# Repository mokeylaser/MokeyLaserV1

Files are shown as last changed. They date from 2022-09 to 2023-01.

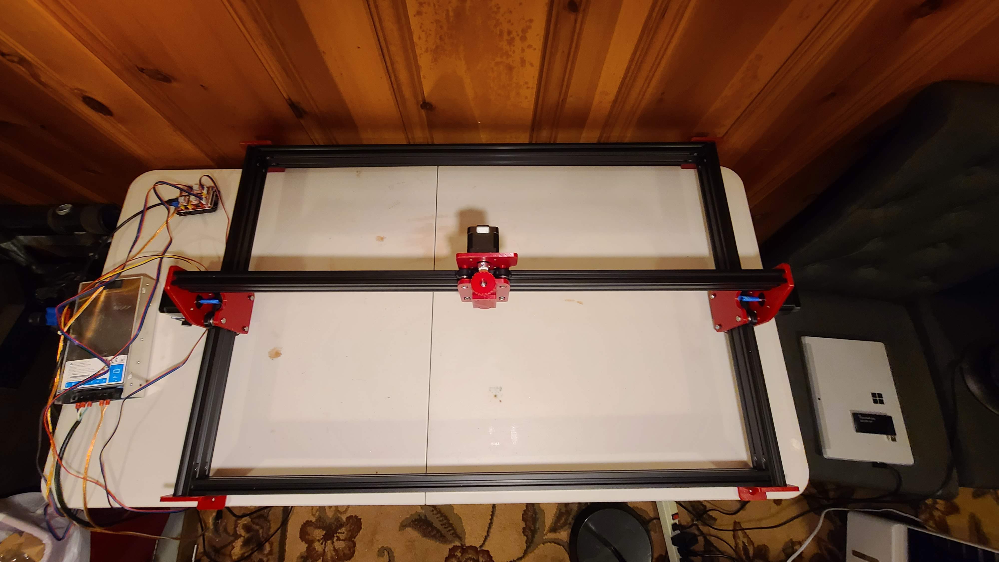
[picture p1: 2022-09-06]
MokeyLaserV1_Images/20220827_191324.jpg

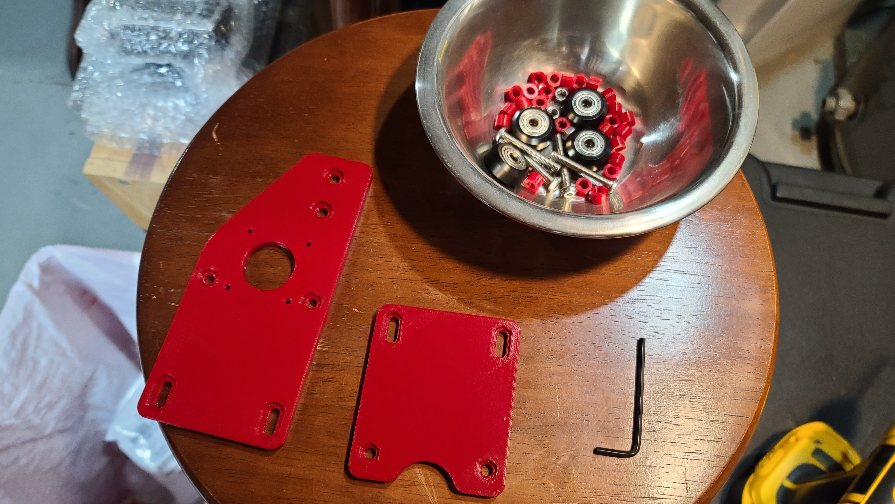
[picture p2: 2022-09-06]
MokeyLaserV1_Images/20220822_205706.jpg

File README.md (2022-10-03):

# MokeyLaserV1
The files needed to build MokeyLaser V1, including 3D models

NOTE: Most lasers, including those shown in my videos, are capable of severely damaging or blinding human eyes and burning or damaging human skin. Any individual working with these devices must be aware of these laser safety issues and take appropriate measures to protect both themselves and others. Read and follow the manufacturer's safety guidelines for your laser. I am NOT responsible for any damage or injury to yourself or any other person resulting from the use, assembly, or operation of any device built from or inspired by my designs. 

Here is the list of purchased parts:
	2M Motor Connecting Cables (pack of 4)	$12.59	Amazon	https://www.amazon.com/dp/B07SLPLPL2?psc=1&ref=ppx_yo2ov_dt_b_product_details
	T-Nuts, 240 Pieces, 2020, M3 M4 M5	$9.98	Amazon	https://www.amazon.com/dp/B08CHJMWP5?psc=1&ref=ppx_yo2ov_dt_b_product_details
	Pan Head Machine Screws, M5-0.8x100mm	$7.99	Amazon	https://www.amazon.com/dp/B07YDJHDP6?psc=1&ref=ppx_yo2ov_dt_b_product_details
	GT2 Pulleys, 20 Teeth, 5mm bore (pack of 5)	$5.99	Amazon	https://www.amazon.com/dp/B077GNZK3J?psc=1&ref=ppx_yo2ov_dt_b_product_details
	2040 Aluminum Extrusion, 1000mm V Slot (pack of 5)	$79.99	Amazon	https://www.amazon.com/dp/B09SHF6VYQ?psc=1&ref=ppx_yo2ov_dt_b_product_details
	GT2 Timing Belt, 5M, 6mm width	$12.99	Amazon	https://www.amazon.com/dp/B08R93QQ8Z?psc=1&ref=ppx_yo2ov_dt_b_product_details
	Printer rollers, V Slot gantry wheel, 625zz (pack of 13)	$11.11	Amazon	https://www.amazon.com/dp/B08B4JDB67?psc=1&ref=ppx_yo2ov_dt_b_product_details
	CNC Shield V3, with A4988 driver modules	$10.99	Amazon	https://www.amazon.com/dp/B07TT3C3HB?psc=1&ref=ppx_yo2ov_dt_b_product_details
	NEMA 17 Stepper Motor, Bipolar, 1.5A, 59.5oz.in (pack of 3)	$28.99	Amazon	https://www.amazon.com/dp/B088BG2QFG?psc=1&ref=ppx_yo2ov_dt_b_product_details
	SainSmart FL55 Laser Module, 455nm, with TTL/PWM 	$159.00	Amazon	https://www.amazon.com/gp/product/B07VHJ7JNW/ref=ppx_yo_dt_b_search_asin_title?ie=UTF8&psc=1
	T-Slot inside corner connector for 2020 extrusion (pack of 20)	$15.99	Amazon	https://www.amazon.com/dp/B07F2K8SN7?psc=1&ref=ppx_yo2ov_dt_b_product_details
	Longrunner mechanical endstop (limit switch) kit (pack of 6)	$9.99	Amazon	https://www.amazon.com/gp/product/B06XTB7WMK/ref=ppx_yo_dt_b_search_asin_title?ie=UTF8&psc=1
	Arduino Uno R3 board, ATmega328p	$17.99	Amazon	https://www.amazon.com/ELEGOO-Board-ATmega328P-ATMEGA16U2-Compliant/dp/B01EWOE0UU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
	Amazon Total	$383.59		
				
	Socket Head Cap Screw: M5-0.80 Tr Size, 35 mm Lg (pack of 50)	$11.62	Grainger	https://www.grainger.com/product/53GJ20
	Socket Head Cap Screw: M3-0.50 Tr Size, 8 mm Lg (pack of 50)	$2.00	Grainger	https://www.grainger.com/product/53GJ01
	Socket Head Cap Screw: M5-0.80 Tr Size, 10 mm Lg (pack of 50)	$4.20	Grainger	https://www.grainger.com/product/53GJ15
	Hex Nut: Plain, 18-8, Stainless Steel, M5-0.80 Thread (pack of 50)	$1.20	Grainger	https://www.grainger.com/product/22YK31
	Grainger Total	$19.02		
	Grand Total	$402.61		
MokeyLaser_V1_Assembly_2022-Sep-06_03-15-41PM

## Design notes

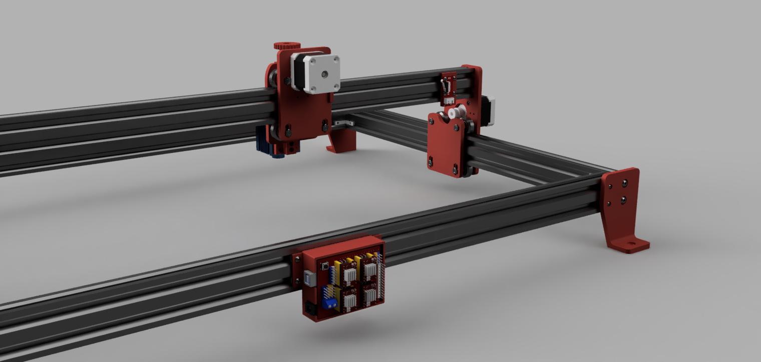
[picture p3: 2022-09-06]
MokeyLaserV1_Images/Arduino and CNC Shield view.jpg

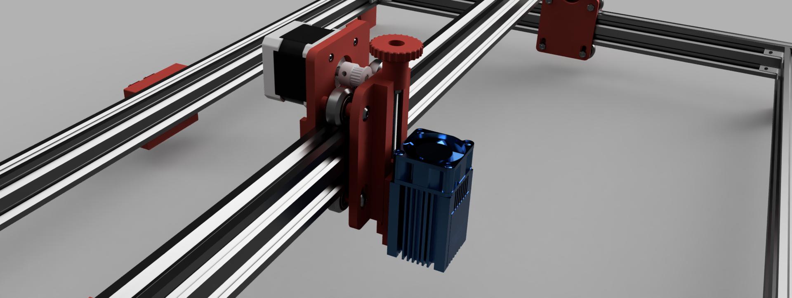
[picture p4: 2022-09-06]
MokeyLaserV1_Images/X-Axis view.jpg

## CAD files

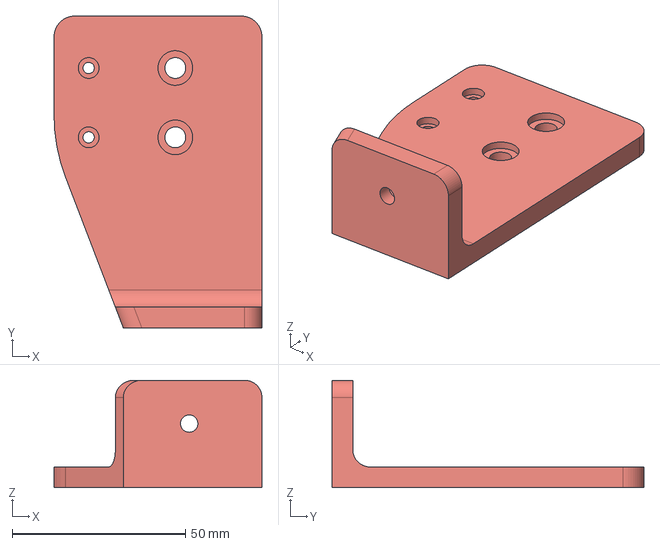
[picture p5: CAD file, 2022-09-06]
CAD_Models_V1/09 Right Leg v1.step
60.0 x 90.0 x 31.0 mm

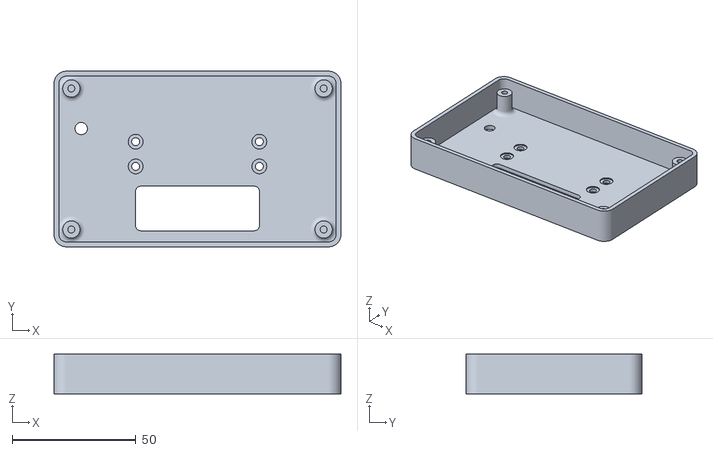
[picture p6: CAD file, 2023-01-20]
MokeyLaser_v1.1/Display Holder TS35-R-V2 v5.stl
116.0 x 71.0 x 16.0

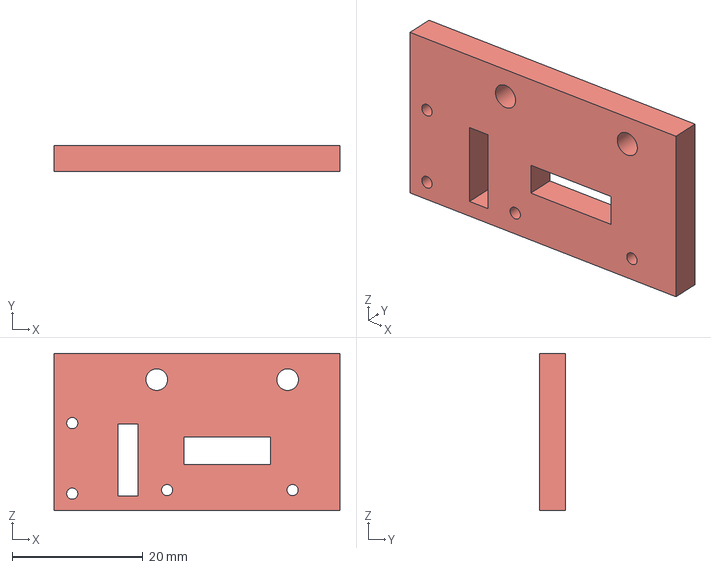
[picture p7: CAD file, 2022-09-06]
CAD_Models_V1/Limit switch mount 4mm v1.step
43.7 x 4.00 x 24.0 mm

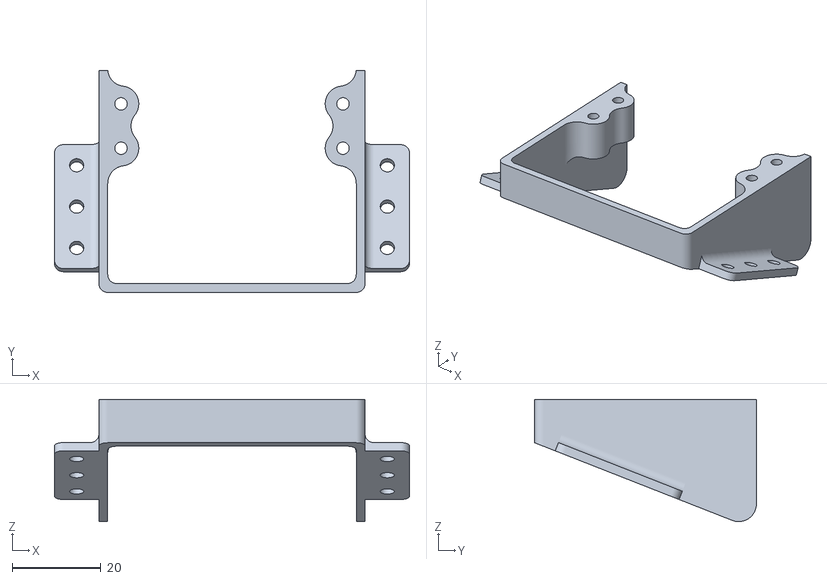
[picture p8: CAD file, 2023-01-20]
MokeyLaser_v1.1/Display Holder TS35-R-V2 Bracket v5.stl
80.0 x 50.0 x 27.5

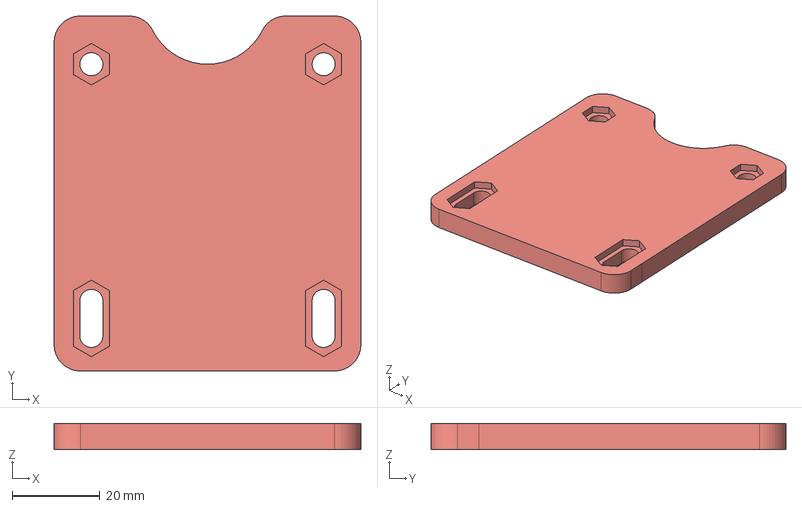
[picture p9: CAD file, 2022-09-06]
CAD_Models_V1/08 Y-Drive Side Panel v1.step
70.0 x 81.0 x 6.00 mm

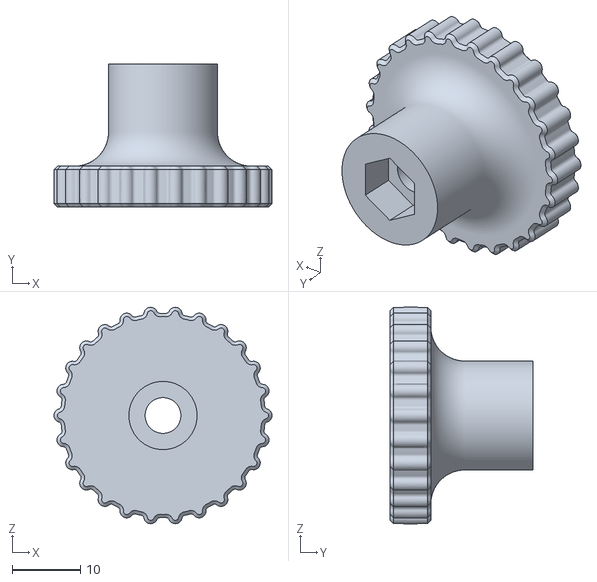
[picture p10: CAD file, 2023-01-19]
MokeyLaser_v1.1/04 Laser Focus Knob v1.stl
32.0 x 21.0 x 31.8

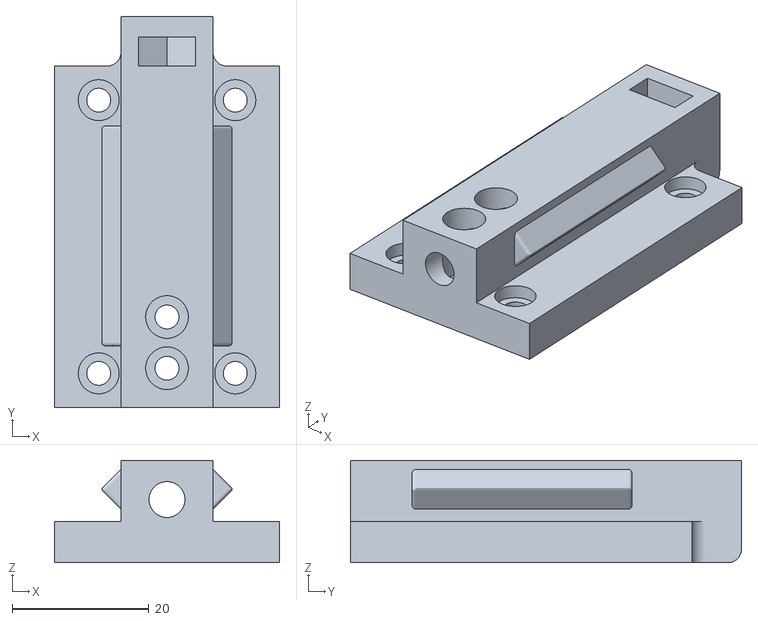
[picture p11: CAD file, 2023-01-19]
MokeyLaser_v1.1/01 Laser Mount 20mm x 40mm M3 v1.stl
33.0 x 57.2 x 15.0

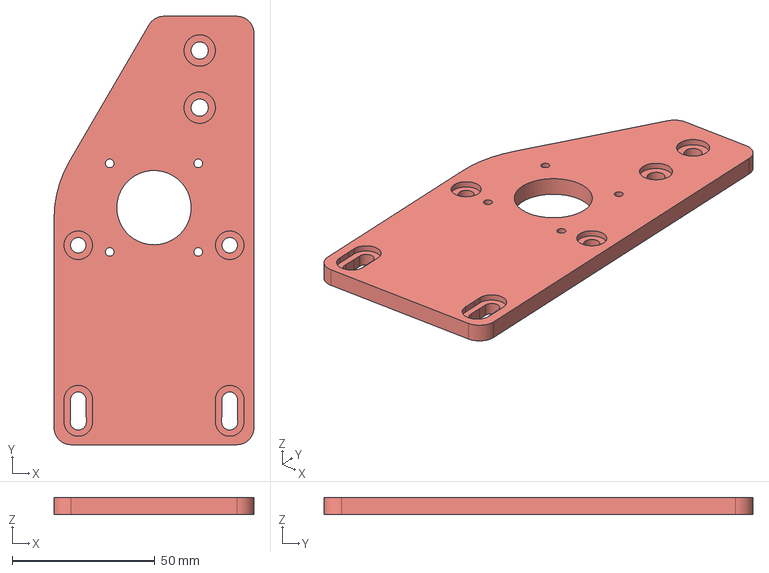
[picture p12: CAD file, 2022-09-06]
CAD_Models_V1/06 Y-Drive Panel R v1.step
70.0 x 150.0 x 6.00 mm

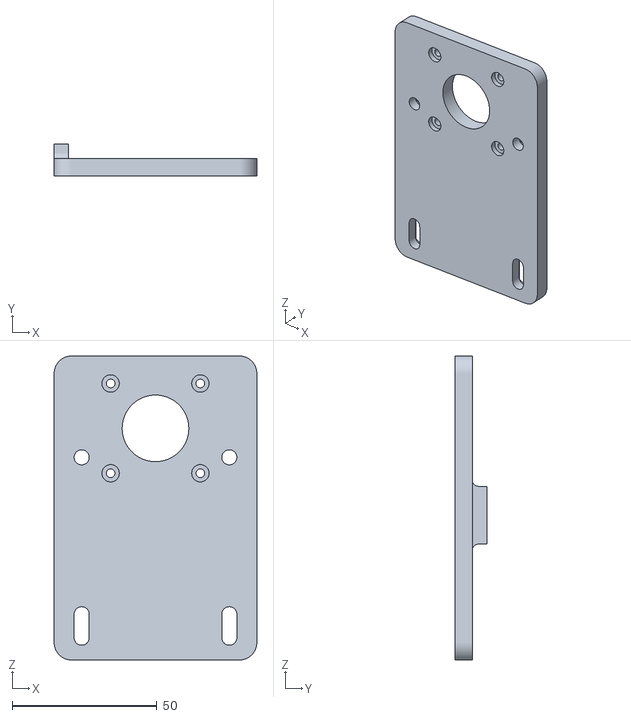
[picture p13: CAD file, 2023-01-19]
MokeyLaser_v1.1/03 X-Axis Stepper Mount v1.stl
70.0 x 11.0 x 105.0

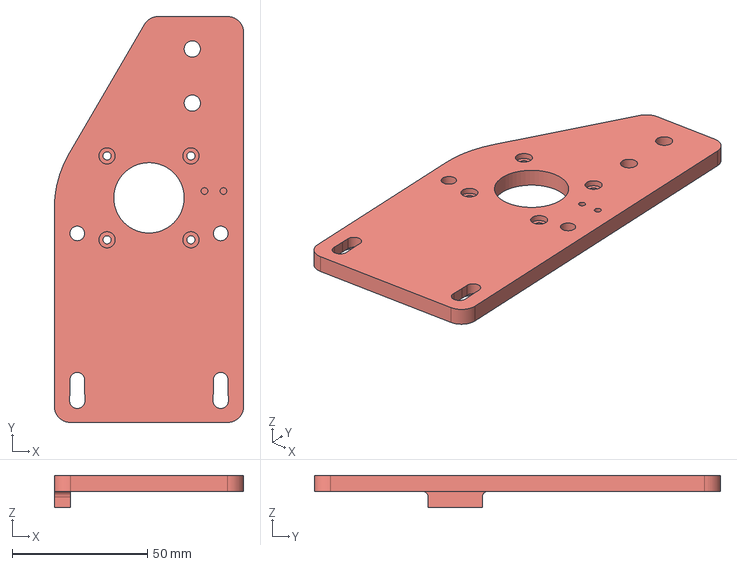
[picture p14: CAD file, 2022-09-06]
CAD_Models_V1/06 Y-Drive Panel L v1.step
70.0 x 150.0 x 12.0 mm

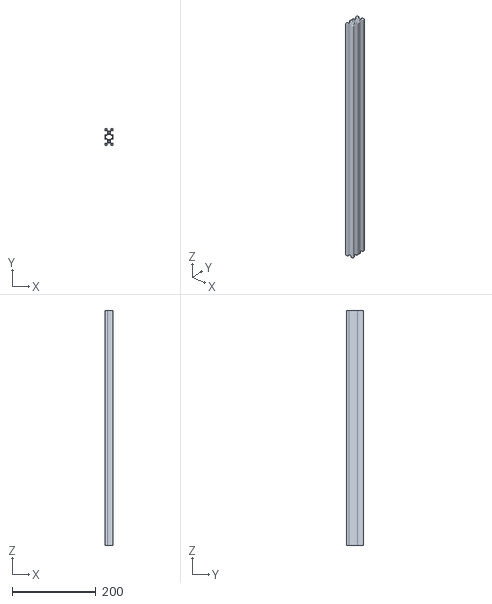
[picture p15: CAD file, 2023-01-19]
MokeyLaser_v1.1/do_not_print_2040 V-Slot 560mm v3.stl
20.0 x 40.0 x 560.0

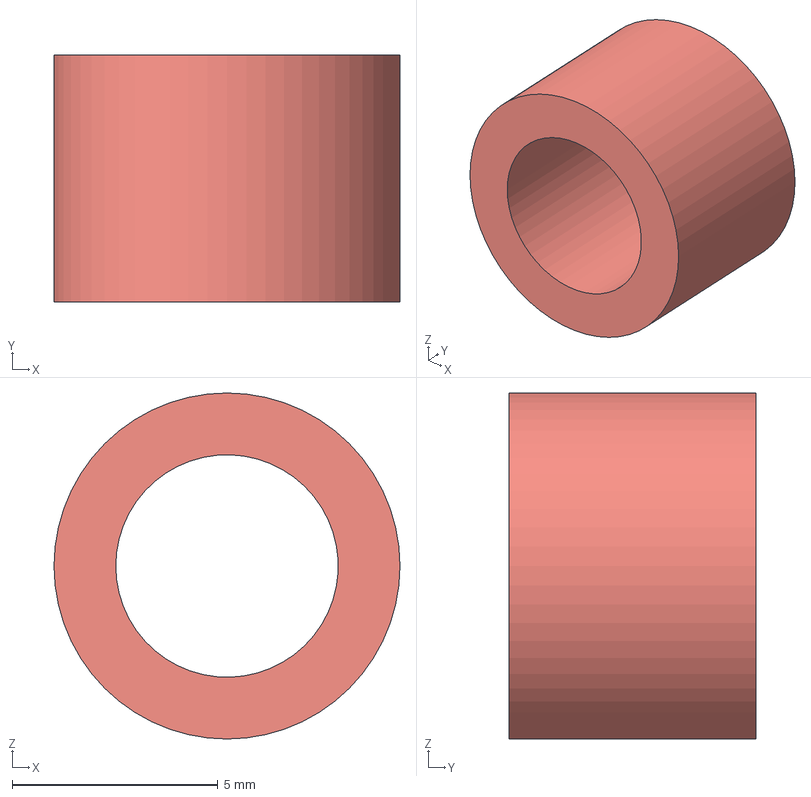
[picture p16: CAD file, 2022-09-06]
CAD_Models_V1/05 V-Wheel Bushing v1.step
8.40 x 6.00 x 8.40 mm

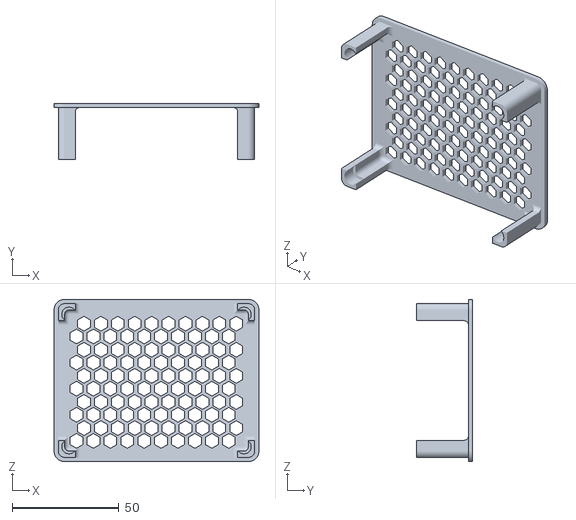
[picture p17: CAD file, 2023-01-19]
MokeyLaser_v1.1/DLC32 Enclosrue Lid.stl
96.0 x 26.4 x 76.0

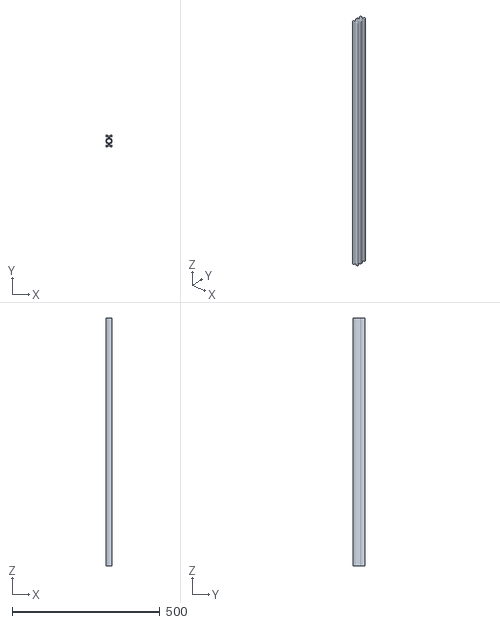
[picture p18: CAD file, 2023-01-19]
MokeyLaser_v1.1/do_not_print_2040 V-Slot 839mm v3.stl
20.0 x 40.0 x 839.0

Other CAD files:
CAD_Models_V1/09 Left Leg v1.step
MokeyLaserV1_STLs/01 Laser Mount v1.stl
CAD_Models_V1/03 X-Axis Stepper Mount v1.step
CAD_Models_V1/02 Laser holder base v1.step
CAD_Models_V1/01 Laser Mount v1.f3d
CAD_Models_V1/01 Laser Mount v1.step
CAD_Models_V1/02 Laser holder base v1.f3d
CAD_Models_V1/03 X-Axis Stepper Mount v1.f3d
CAD_Models_V1/04 Laser Focus Knob v1.f3d
CAD_Models_V1/04 Laser Focus Knob v1.step
CAD_Models_V1/05 V-Wheel Bushing v1.f3d
CAD_Models_V1/06 Y-Drive Panel L v1.f3d
CAD_Models_V1/06 Y-Drive Panel R v1.f3d
CAD_Models_V1/08 Y-Drive Side Panel v1.f3d
CAD_Models_V1/09 Left Leg v1.f3d
CAD_Models_V1/09 Right Leg v1.f3d
CAD_Models_V1/Limit switch mount 4mm v1.f3d
CAD_Models_V1/Uno and CNC Shield holder v2.f3d
CAD_Models_V1/Uno and CNC Shield holder v2.step
MokeyLaserV1_STLs/02 Laser holder base v1.stl
MokeyLaserV1_STLs/03 X-Axis Stepper Mount v1.stl
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

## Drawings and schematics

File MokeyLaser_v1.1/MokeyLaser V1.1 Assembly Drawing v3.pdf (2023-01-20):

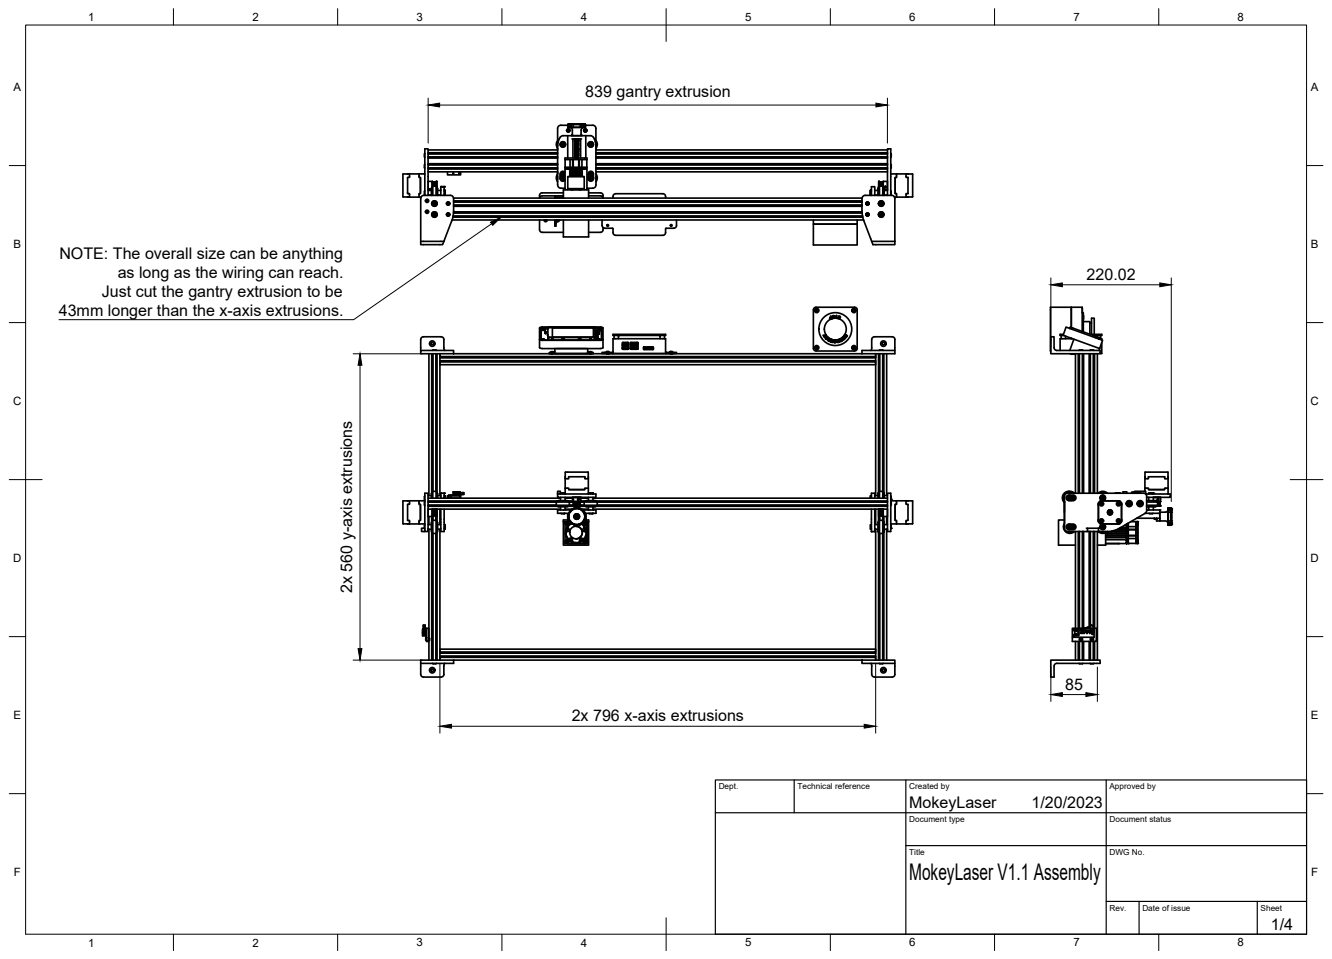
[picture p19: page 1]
Dept.; Technical reference; Created by; Approved by; Document type; Document status; Title; DWG No.; Rev.; Date of issue; Sheet; MokeyLaser V1.1 Assembly; 2x 796 x-axis extrusions; 839 gantry extrusion

NOTE: The overall size can be anything

as long as the wiring can reach.
Just cut the gantry extrusion to be
43mm longer than the x-axis extrusions.

MokeyLaser 2x 560 y-axis extrusions

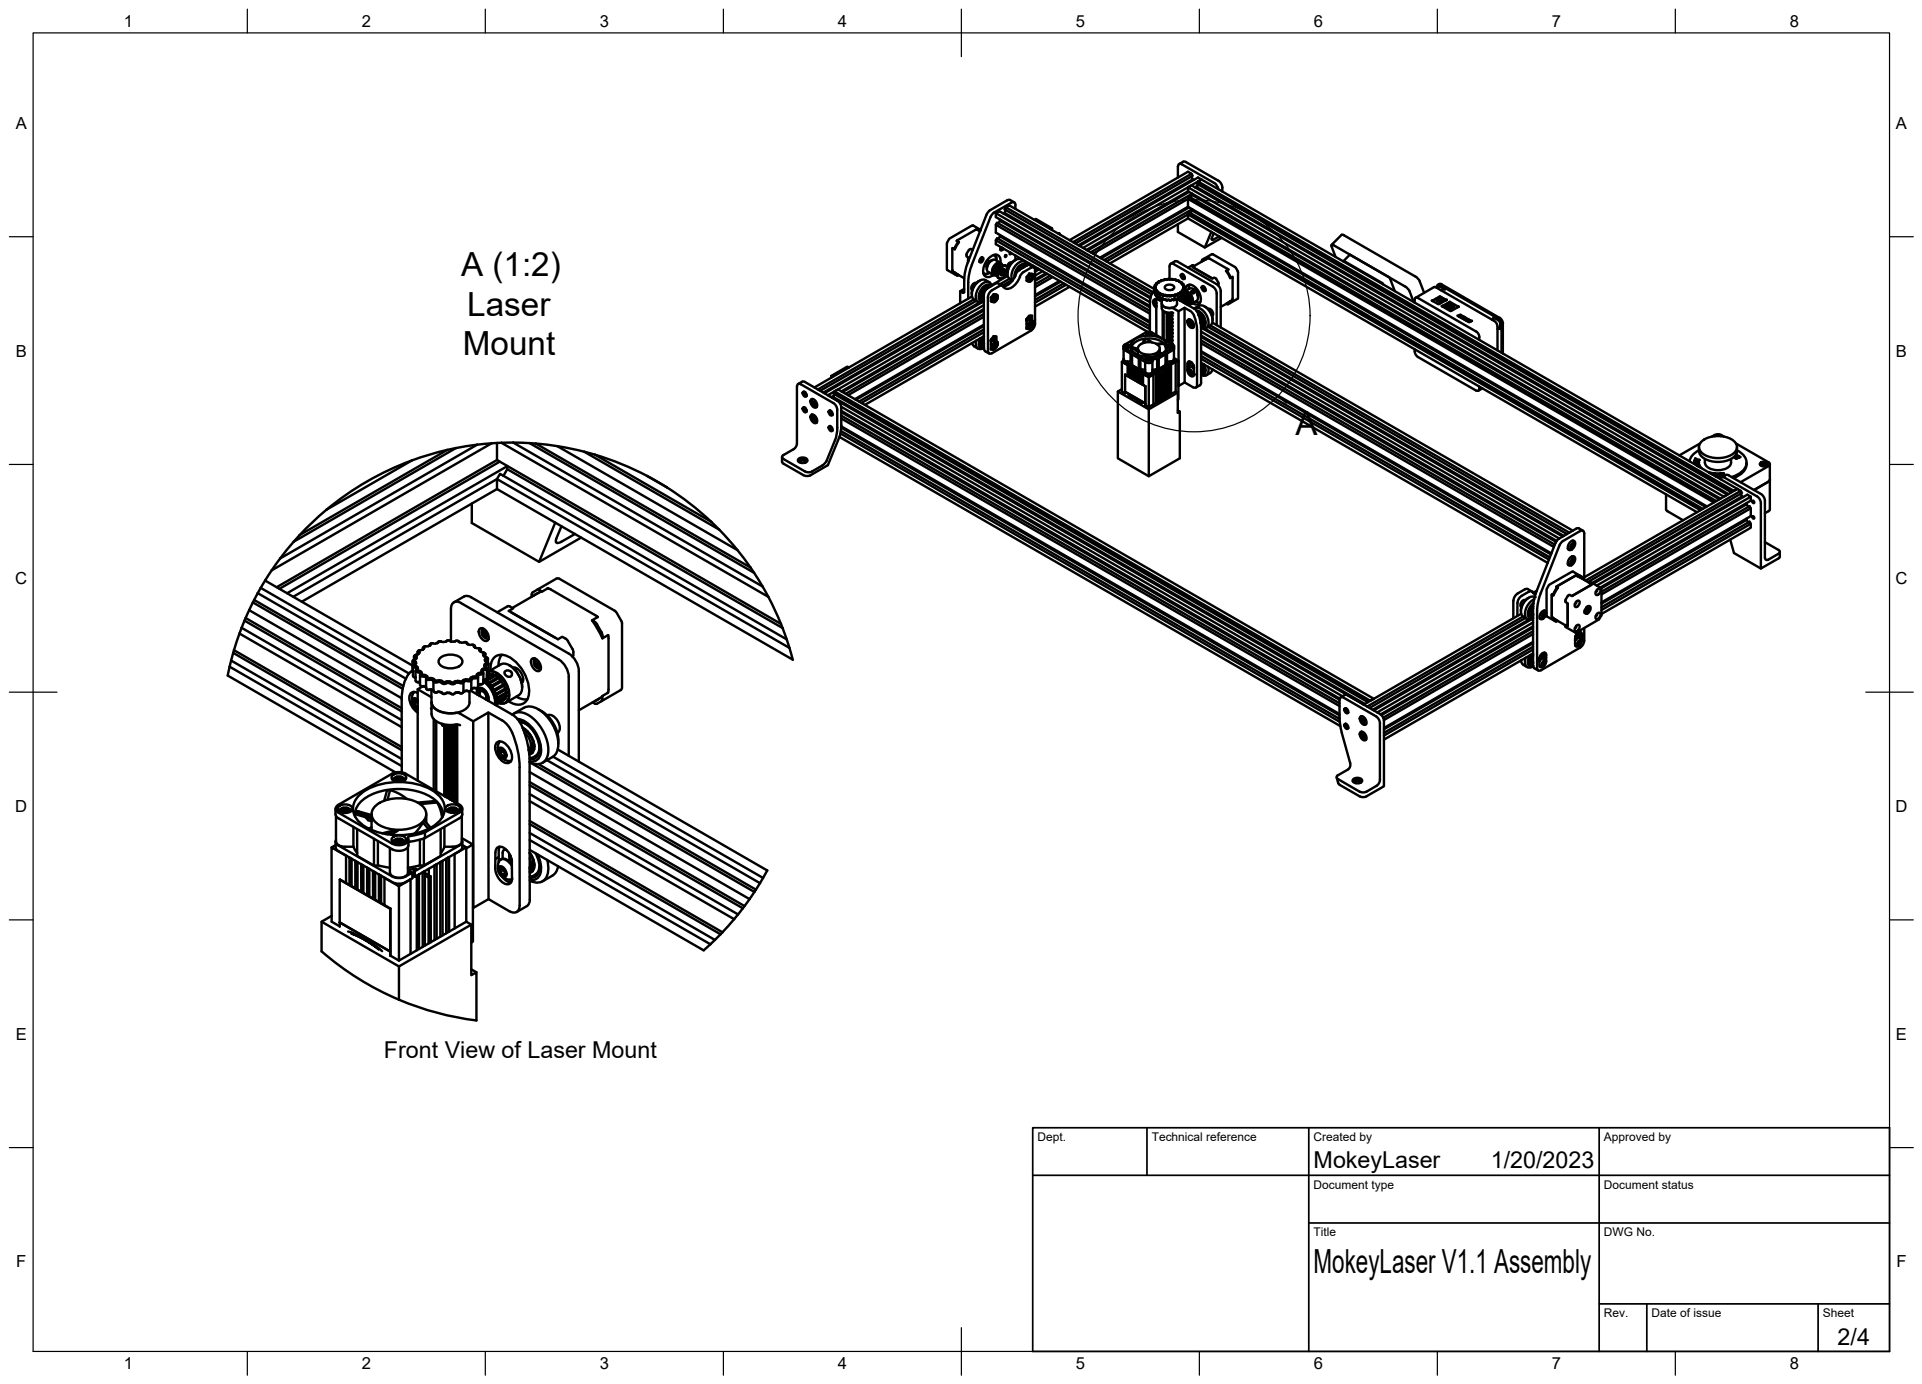
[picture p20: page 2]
Title; DWG No.; MokeyLaser V1.1 Assembly

Front View of Laser Mount

Dept. | Technical reference | Created by MokeyLaser 1/20/2023 | Approved by

Document type | Document status

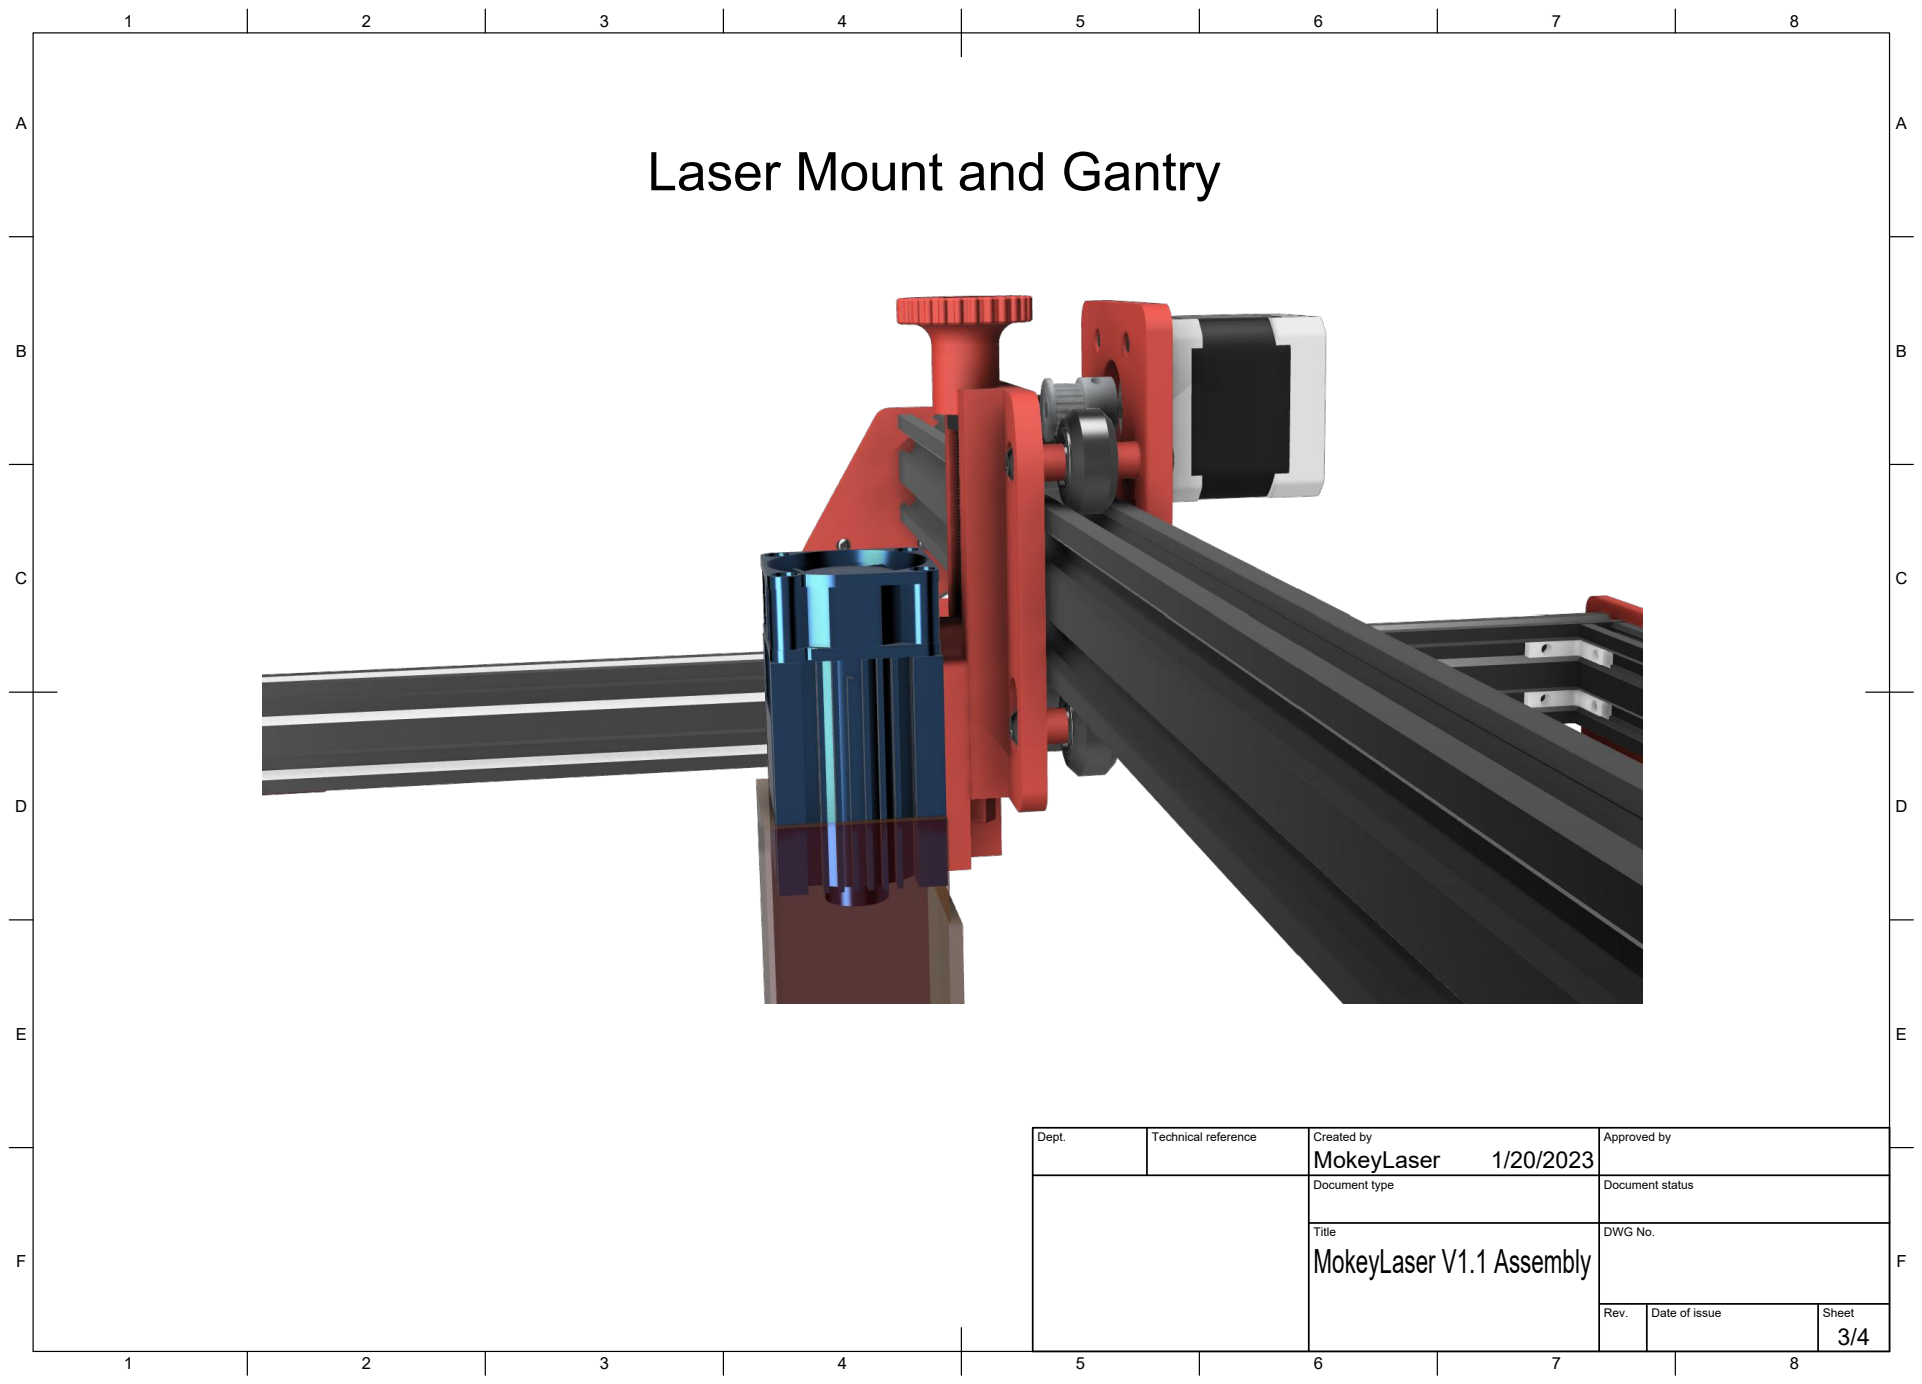
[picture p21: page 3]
Title; DWG No.; MokeyLaser V1.1 Assembly

Laser Mount and Gantry

Dept. | Technical reference | Created by MokeyLaser 1/20/2023 | Approved by

Document type | Document status

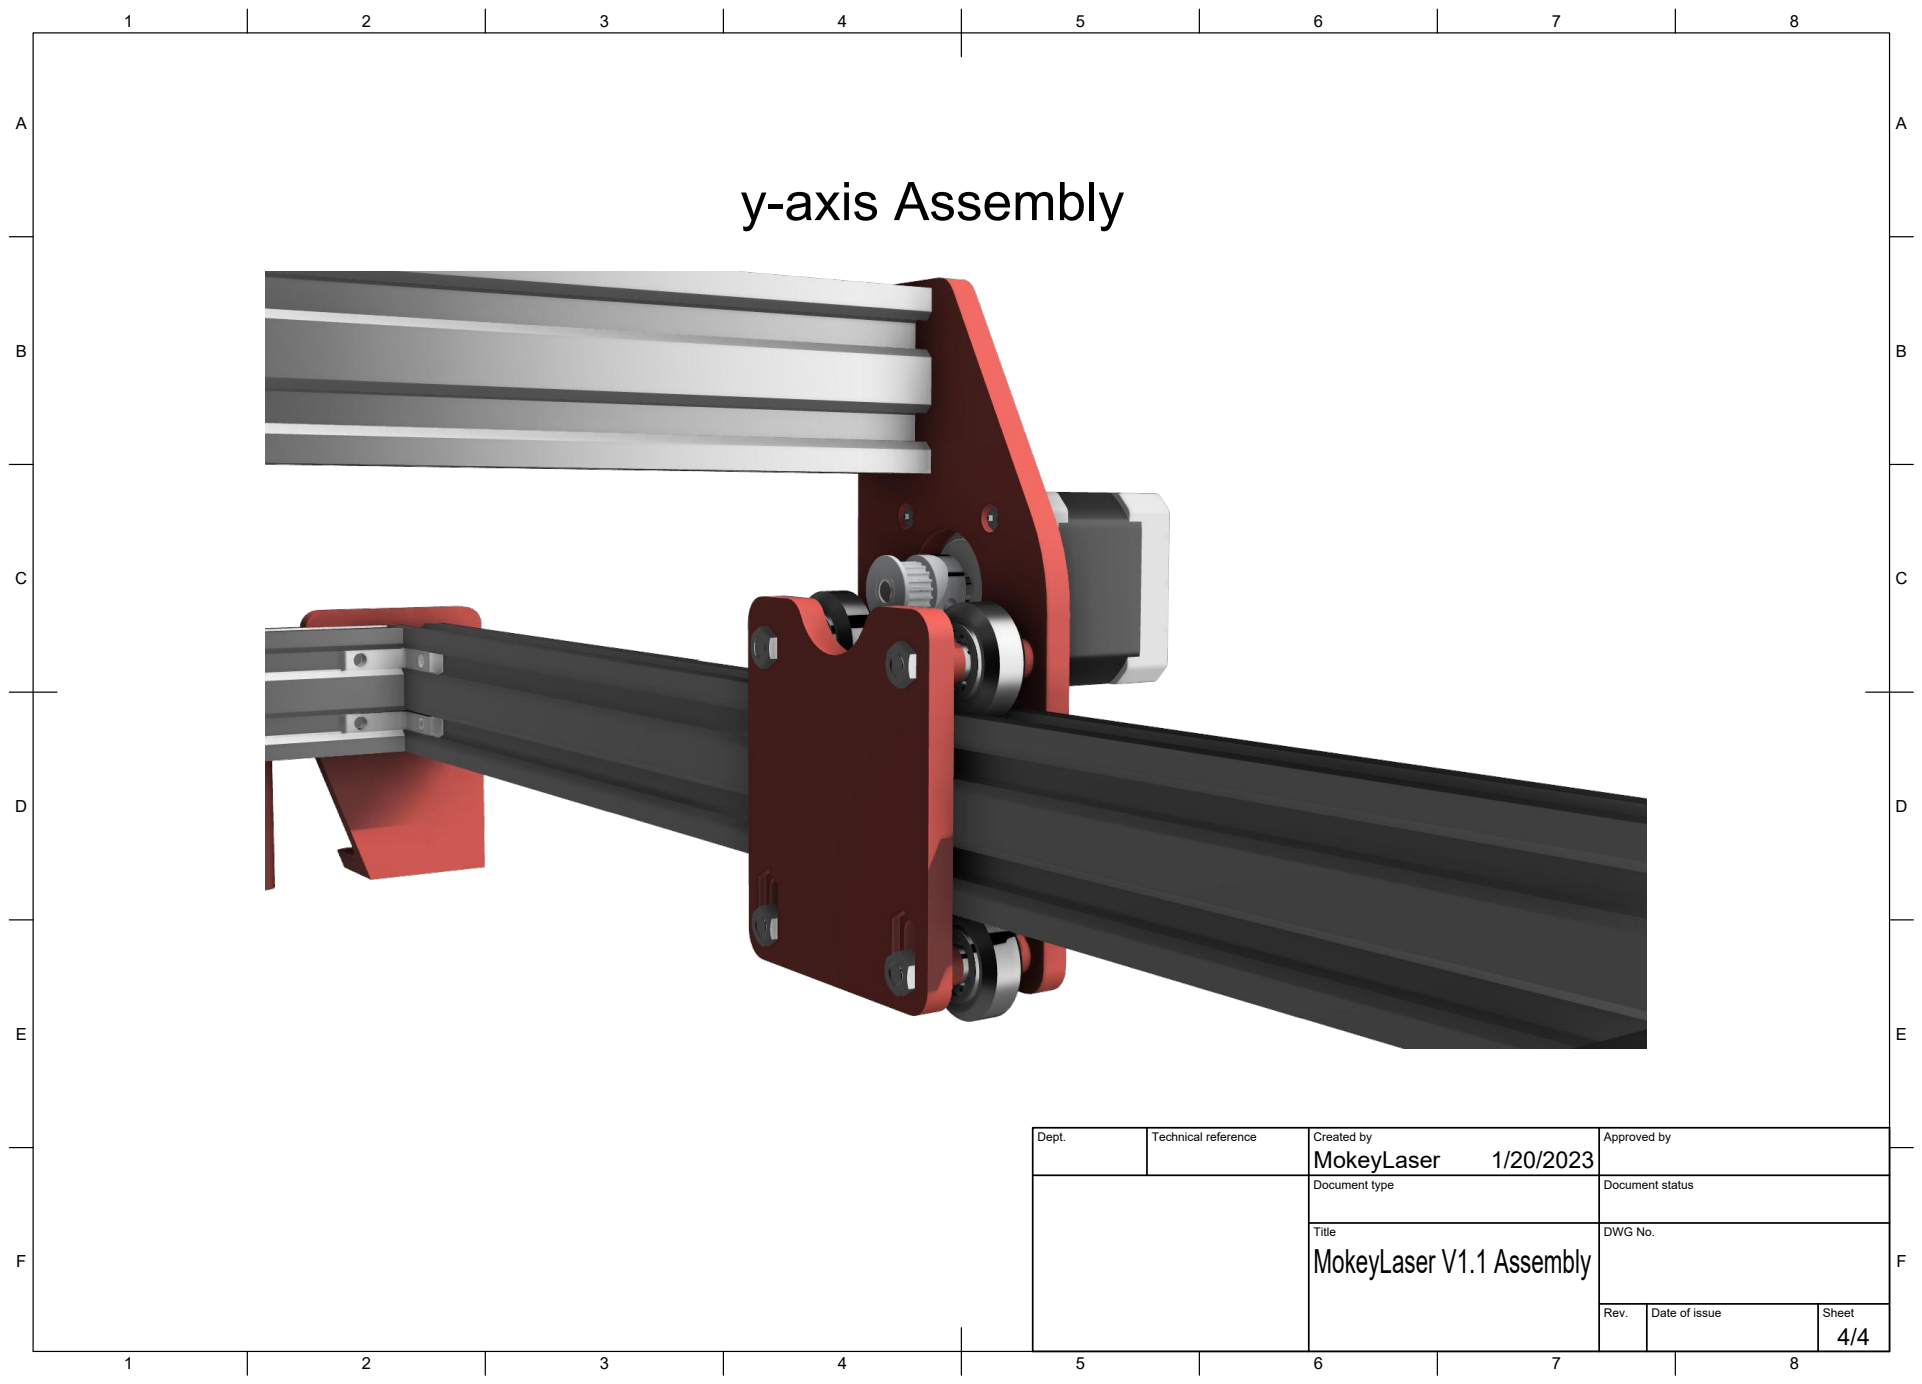
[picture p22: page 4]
Title; DWG No.; MokeyLaser V1.1 Assembly; y-axis Assembly

Dept. | Technical reference | Created by MokeyLaser 1/20/2023 | Approved by

Document type | Document status

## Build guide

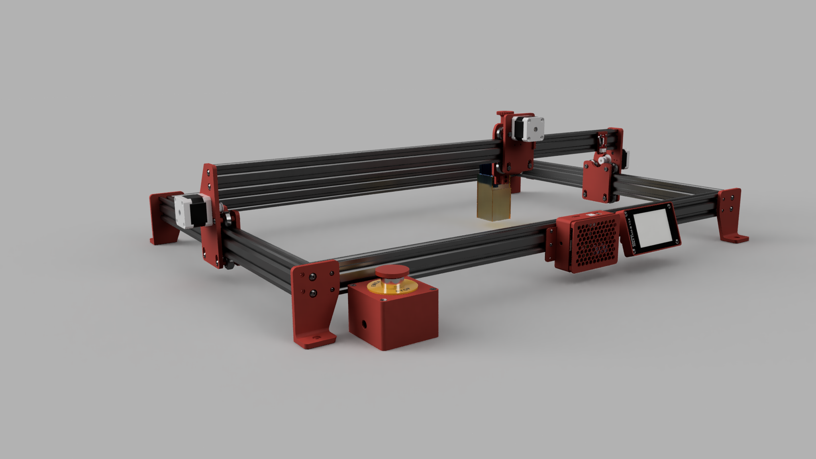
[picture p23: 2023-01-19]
MokeyLaser_v1.1/MokeyLaser_V1.1_Assembly_2022-Sep-30.png

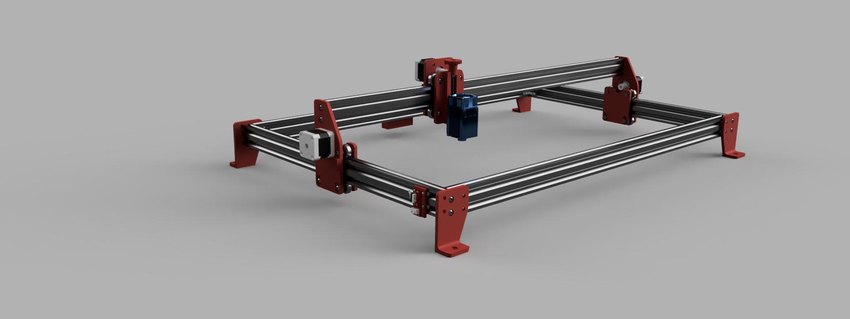
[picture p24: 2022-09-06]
MokeyLaserV1_Images/MokeyLaser_V1_Assembly_2022-Sep-06_03-15-41PM.jpg

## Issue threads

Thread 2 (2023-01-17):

missing STL for v1.1 controller and touchscreen

rd636, 2023-01-17:
Please add your STL models for the MKS DCL32 controller and 3.5" touchscreen.

mokeylaser, 2023-01-19:
I have added all files including the MKS DLC32 controller and touchscreen to the V1.1 folder.
https://github.com/mokeylaser/MokeyLaserV1/tree/main/MokeyLaser_v1.1
Thank you, and let me know of any other issues.

rd636, 2023-02-09:
I don't know if you can direct message this way- but I thought I'd try.

Thank you for your github post and additional files.  I've may a 900x900
with some small tweaks.
If this email finds you and you reply, I'd be happy to share pics.

I'm having a bit of trouble getting my LT-4LDS-V2 80w LaserTree to fire,
but the build went well and it moves fast.

Sincerely,

RD636

Closed 2023-01-19.

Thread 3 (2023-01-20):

STL was rendered icorrectly.

rd636, 2023-01-20:
Thank you so much for publishing the DLC parts.  I've started printing.  The display STL file looks like it has a model TFT inside by mistake.  Will you please repost.
https://github.com/mokeylaser/MokeyLaserV1/tree/main/MokeyLaser_v1.1/Display Holder TS35-R-V2 v5.stl

mokeylaser, 2023-01-20:
I reposted the file without the display or mounting screws (my apologies), and I added the bracket, which is needed to mount the display holder to the engraver frame.

Closed 2023-01-20.

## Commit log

2022-09-12 Add files via upload
    This is the full assembly of the Mokey Laser, with the MKS DLC32 controller board instead of the Arduino/CNC Shield. It is a Fusion 360 archive file.
2022-09-12 Update README.md
    Added rendering of assembly
2023-01-19 Add files via upload
    This laser holder has a 16mm x 40mm hole pattern for M3 screws to fit "LA-2" laser modules.
    [01 Laser Mount LA-2 v3.stl]
2023-01-19 Add files via upload
    The parts beginning with "do_not_print" are purchased parts, provided for modeling purposes only.
    [01 Laser Mount 16mm x 40mm M3 LA-2 v3.stl, 01 Laser Mount 20mm x 40mm M3 v1.stl, 02 Laser holder base v1.stl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]
2023-01-19 Add files via upload
    Uploaded another render of the fully assembled engraver.
2023-01-20 Delete Display Holder TS35-R-V2 v5.stl
    This STL file erroneously included the display and mounting hardware.
2023-01-20 Add files via upload
    Replaced Display Holder TS35-R-V2 v5 because original file included the display and hardware. ALSO added Display Holder TS35-R-V2 Bracket v5, which is needed to mount the display holder to the engraver frame.
    [Display Holder TS35-R-V2 Bracket v5.stl, Display Holder TS35-R-V2 v5.stl]
2023-01-20 Add files via upload
    Uploaded the early beginnings of what will be a full assembly drawing.
